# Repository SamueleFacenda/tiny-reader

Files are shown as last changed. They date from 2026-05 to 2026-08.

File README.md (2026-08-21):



<!-- PROJECT SHIELDS -->
[][contributors-url]
[][forks-url]
[][stars-url]
[][issues-url]
[][license-url]
[][workflow-url]

<!-- PROJECT LOGO -->
<div align="center">
    <a href="https://github.com/SamueleFacenda/tiny-reader">
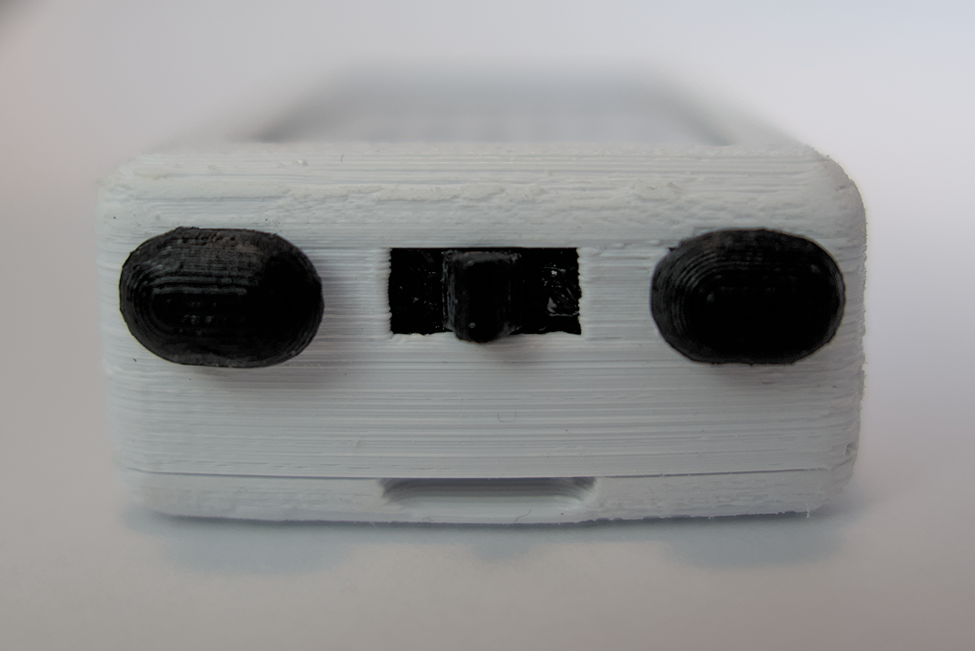
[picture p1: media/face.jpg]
        
    </a>
    <h3 align="center">TinyReader</h3>
    <p align="center">
        TinyReader is a small and easy to assembly e-book reader. 
        <br />
        It is intended for mobile reading, it's highly pocketable and supports wireless ebooks transfer. 
        <br />
        <a href="https://github.com/SamueleFacenda/tiny-reader"><strong>Explore the docs »</strong></a>
        <br />
        <br />
        <a href="#gallery">View Pictures</a>
        &middot;
        <a href="https://github.com/SamueleFacenda/tiny-reader/issues">Report Bug</a>
        &middot;
        <a href="https://github.com/SamueleFacenda/tiny-reader/issues">Request Feature</a>
    </p>
</div>

<!-- TABLE OF CONTENTS -->
<details>
    <summary>Table of Contents</summary>
    <ol>
        <li>
            <a href="#about-the-project">About The Project</a>
            <ul>
                <li><a href="#built-with">Built With</a></li>
            </ul>
        </li>
        <li>
            <a href="#getting-started">Getting Started</a>
            <ul>
                <li><a href="#prerequisites">Prerequisites</a></li>
                <li><a href="#installation">Installation</a></li>
            </ul>
        </li>
        <li><a href="#docs">Docs</a></li>
        <li><a href="#usage">Usage</a></li>
        <li><a href="#roadmap">Roadmap</a></li>
        <li><a href="#contributing">Contributing</a></li>
        <li><a href="#license">License</a></li>
        <li><a href="#contact">Contact</a></li>
        <li><a href="#acknowledgments">Acknowledgments</a></li>
        <li><a href="#star-history">Star History</a></li>
        <li><a href="#gallery">Gallery</a></li>
    </ol>
</details>

<!-- ABOUT THE PROJECT -->
## About The Project

<div style="width:40%; margin: auto;">

e reader size in hand
</div>

TinyReader is a small and easy to assembly e-book reader. It is intended for mobile reading, it's 
highly pocketable and supports wireless ebooks transfer. 

The project is experimental and practical rather than polished. Mechanical fit, battery choice, and power behavior depend on the exact hardware configuration and enclosure you build around it.

Features:
- low battery usage thanks to e-ink display and automatic deep sleep
- custom font with latin-1 encoding support
- fast page turning thanks to partial refreshes
- high readability: the font is actually bigger than a normal book font,
combined with a small display which requires minimal eye movement it results
in an high read comfort.

<p align="right">(<a href="#readme-top">back to top</a>)</p>

### Built With

* Arduino CLI
* ESP32 platform support through Nix
* LittleFS
* GxEPD2
* Adafruit GFX Library
* ArduinoJson
* OpenSCAD for enclosure work

### Hardware and cost

TinyReader primary goals were to build a pocketable and cheap ebooks reader.
The total cost is lower than 30€ (20€ without expeditions), the components used are:
- [CrowPanel ESP32 2.13 display board](https://www.elecrow.com/crowpanel-esp32-2-13-e-paper-hmi-display-with-122-250-resolution-black-white-color-driven-by-spi-interface.html): 11.9$
- A 700/800mAh LiPo battery (602060 or 603040): <10€
- 3d printed enclosure: <0.1€

<p align="right">(<a href="#readme-top">back to top</a>)</p>

<!-- GETTING STARTED -->
## Getting Started

The repository includes a Nix flake, so the Arduino toolchain and project dependencies can be gathered with `nix develop`.

The scad source is available here or the rendered stl can be downloaded [directly from printables](https://www.printables.com/model/1741918-tinyreader-case-elecrow-crowpanel-esp32-213).

### Prerequisites

* Nix with flakes enabled
* The CrowPanel ESP32 2.13 E-Paper HMI display board
* A suitable LiPo battery

### Installation

1. Clone the repo
     ```sh
     git clone https://github.com/SamueleFacenda/tiny-reader.git
     ```
2. Enter the development shell
     ```sh
     nix develop
     ```
3. Compile the sketch with Arduino CLI
     ```sh
     arduino-cli compile --fqbn esp32:esp32:esp32s3
     ```
4. Flash the firmware to the board (port may vary)
    ```sh
    arduino-cli upload -p /dev/ttyUSB0 --fqbn esp32:esp32:esp32s3 --verbose 
    ```

The flake provides the Arduino CLI, ESP32 board packages, Python serial support, and OpenSCAD.

The repository ships a [partitions.csv](partitions.csv) that drops OTA and hands the whole 8MB
flash to books, giving the library 6.62MB where the stock layout allows 1.44MB. That needs one
extra piece: the bootloader the ESP32 core builds declares 4MB and cannot be corrected while
flashing, so a table this large would not boot with it. The flake regenerates a correct one and
the development shell drops it in as `bootloader.bin`, which is why `nix develop` (or direnv) is
required before flashing rather than merely convenient. The first flash with this table
invalidates any filesystem already on the device: the reader shows a LittleFS error on boot, hold
the OK button for a couple of seconds to format it, then upload the books again.

### Assembly

No tool is actually required for the device assembly. Some more work might be required depending on
the battery size.

The board features a non so common SH1.0-2Pin battery socket so an adaptor might be necessary.

If you are using a 603040 battery you might want to remove the UART and GPIO ports to reduce the
device height. For 602060 batteries it's not necessary, they fit between the ports (but have smaller
capacity)

<p align="right">(<a href="#readme-top">back to top</a>)</p>

## Docs

* [tiny-reader.ino](tiny-reader.ino) is the Arduino entrypoint. It wires the display, input, storage, and Wi-Fi flow together.
* [tiny_reader_2-13_case.scad](tiny_reader_2-13_case.scad) is the OpenSCAD enclosure model. You can find the rendered version
[here on pritables](https://www.printables.com/model/1741918-tinyreader-case-elecrow-crowpanel-esp32-213).
* The OpenSCAD model references a CrowPanel board STL for fit checking and conversion. The board asset can be converted from the vendor archive at [00-2-13_view_asm.rar](https://github.com/Elecrow-RD/CrowPanel-ESP32-2.13-E-paper-HMI-Display-with-122-250/blob/ca6f62e88c83c108be3904d36e00ded4f55bb68f/3D%20file/00-2-13_view_asm.rar).
* The firware is built with customization in mind, take a look at [the config file](src/Config.h) for
all the available customization options (other boards might be supported as well). Setting
`LEFT_HANDED` there rotates the screen and swaps the button pairs for holding the device the
other way round.

<!-- USAGE EXAMPLES -->
## Usage

1. Flash the sketch to the board.
2. Upload plain text books through the Wi-Fi page. The page converts them in the browser:
UTF-8 becomes latin-1 (accents are kept, typographic quotes and dashes are flattened),
hyphenated line breaks are rejoined, and paragraphs are unwrapped so the reader can fill
every line of the small screen.
3. Use the physical buttons to navigate the library, reading view, and status screens. Presses
are never lost while the screen is updating, so the lever can be pushed repeatedly to scroll
several pages ahead in one refresh.
4. Press OK while reading for a deep clean refresh, which clears the ghosting that sunlight
makes visible.
5. Let the device enter deep sleep when idle to preserve battery life. Between page turns it
already drops into light sleep, waking on a button.
6. Wake from the deep sleep using the `home` button.

See the source files for the screen flow and button mapping.

<p align="right">(<a href="#readme-top">back to top</a>)</p>

<!-- ROADMAP -->
## Roadmap

- Improve the library and book navigation flow.
- Refine the Wi-Fi user interface.
- Add a dedicated sleep-screen experience.
- Improve battery status reporting when a usable ADC input is available.
- Update only the necessary parts of the screen during Wi-Fi uptime refreshes.
- Evaluate compressed book storage to reduce flash usage.
- Reduce friction in navigation and return paths between screens.

See the [open issues](https://github.com/SamueleFacenda/tiny-reader/issues) for the current list of planned work.

<p align="right">(<a href="#readme-top">back to top</a>)</p>

<!-- CONTRIBUTING -->
## Contributing

Contributions are welcome. If you have an idea that would make TinyReader better, open an issue or submit a pull request with a clear description of the change.

1. Fork the Project
2. Create your Feature Branch (`git checkout -b feature/AmazingFeature`)
3. Commit your Changes (`git commit -m 'Add some AmazingFeature'`)
4. Push to the Branch (`git push origin feature/AmazingFeature`)
5. Open a Pull Request

<p align="right">(<a href="#readme-top">back to top</a>)</p>

<!-- LICENSE -->
## License

Distributed under the EUPL. See [LICENSE.md](LICENSE.md) for more information.

<p align="right">(<a href="#readme-top">back to top</a>)</p>

<!-- CONTACT -->
## Contact

Project Link: [https://github.com/SamueleFacenda/tiny-reader](https://github.com/SamueleFacenda/tiny-reader)

Use GitHub issues for bugs, feature requests, and build questions.

<p align="right">(<a href="#readme-top">back to top</a>)</p>

<!-- ACKNOWLEDGMENTS -->
## Acknowledgments

* [Original case designer](https://www.printables.com/model/1566902-case-for-crowpanel-213-epaper)
* [CrowPanel ESP32 2.13 E-Paper HMI display](https://example.com/tinyreader-crowpanel-esp32-2-13)
* [Nix](https://nixos.org/)
* [Arduino CLI](https://arduino.github.io/arduino-cli/latest/)

<p align="right">(<a href="#readme-top">back to top</a>)</p>

<!-- GALLERY -->
## Gallery

### TinyReader UI
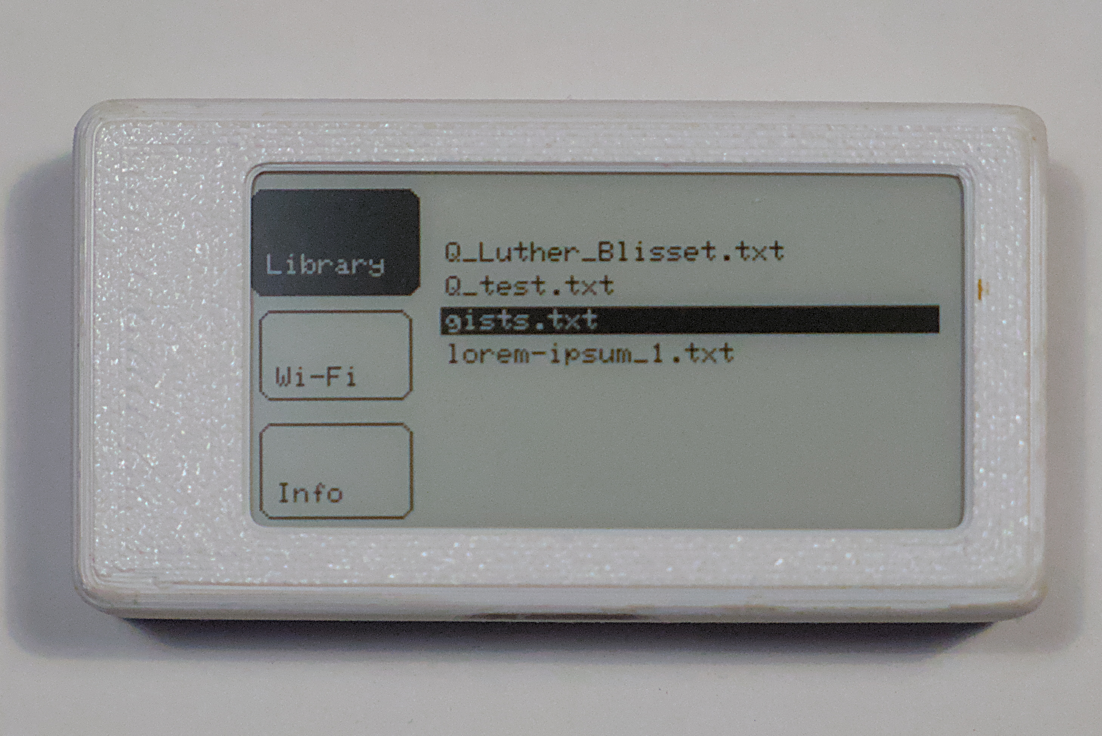
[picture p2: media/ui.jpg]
e reader ui


### TinyReader buttons interface
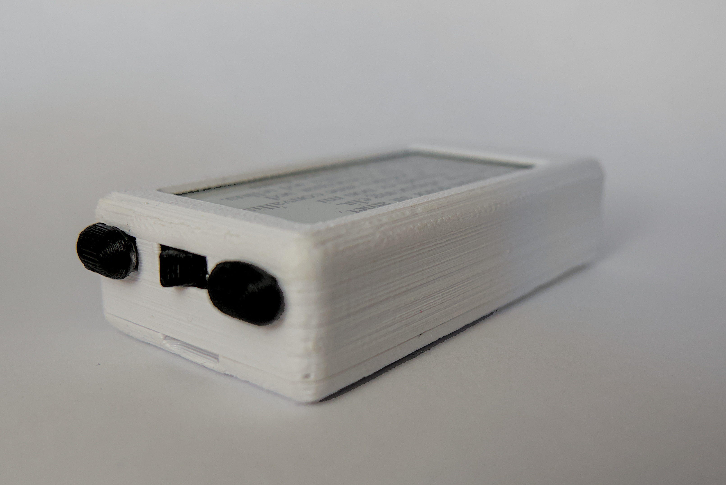
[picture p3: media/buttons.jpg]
buttons view


### TinyReader internal design
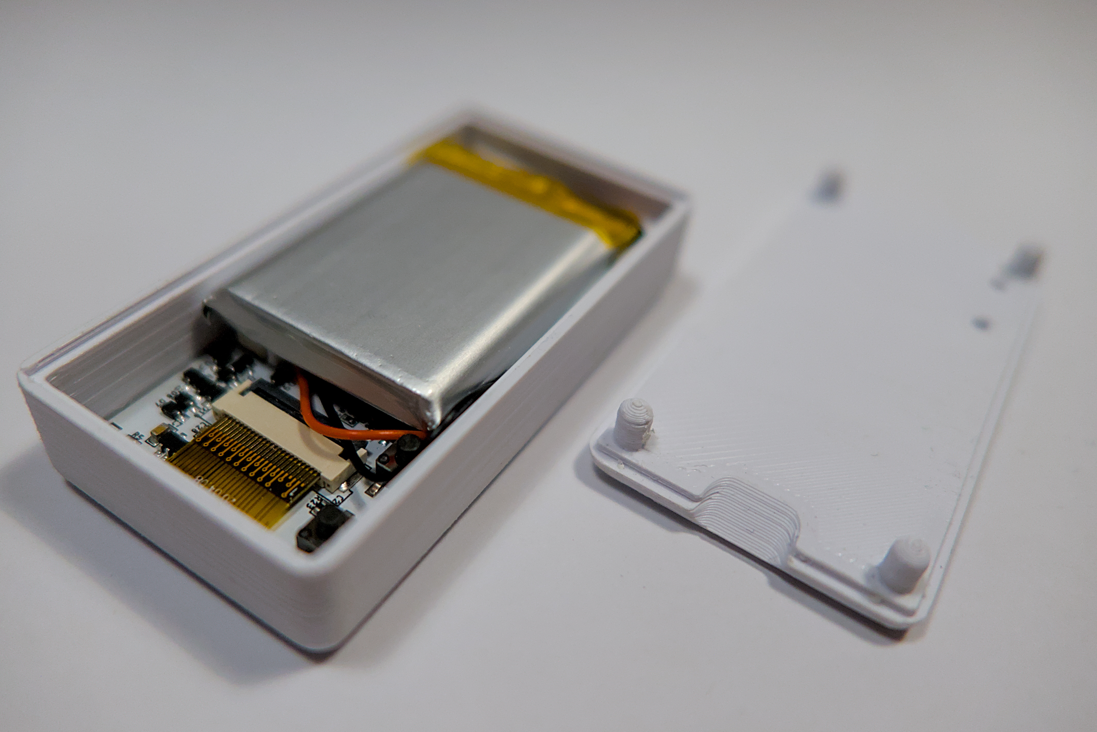
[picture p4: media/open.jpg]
board opened


## Star History

Star History Chart (https://www.star-history.com/#SamueleFacenda/tiny-reader&Date)

<!-- MARKDOWN LINKS & IMAGES -->
[contributors-shield]: https://img.shields.io/github/contributors/SamueleFacenda/tiny-reader.svg?style=for-the-badge
[contributors-url]: https://github.com/SamueleFacenda/tiny-reader/graphs/contributors
[forks-shield]: https://img.shields.io/github/forks/SamueleFacenda/tiny-reader.svg?style=for-the-badge
[forks-url]: https://github.com/SamueleFacenda/tiny-reader/network/members
[stars-shield]: https://img.shields.io/github/stars/SamueleFacenda/tiny-reader.svg?style=for-the-badge
[stars-url]: https://github.com/SamueleFacenda/tiny-reader/stargazers
[issues-shield]: https://img.shields.io/github/issues/SamueleFacenda/tiny-reader.svg?style=for-the-badge
[issues-url]: https://github.com/SamueleFacenda/tiny-reader/issues
[license-shield]: https://img.shields.io/github/license/SamueleFacenda/tiny-reader.svg?style=for-the-badge
[license-url]: https://github.com/SamueleFacenda/tiny-reader/blob/main/LICENSE.md
[workflow-shield]: https://img.shields.io/github/actions/workflow/status/SamueleFacenda/tiny-reader/main.yml?style=for-the-badge
[workflow-url]: https://github.com/SamueleFacenda/tiny-reader/actions/workflows/main.yml

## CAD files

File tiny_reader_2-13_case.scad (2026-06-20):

ZERO_GAP = $preview ? 0.1 : 0; // Put at zero in rendering, used to prevent zero thickness issues in difference() operations during preview
EPS = 0.01; // Small but non zero value

module rounded_trapezoid(w, h, r, r2 = -1, off = -1) {
    off_val = off < 0 ? h : off;
    r2_val = r2 < 0 ? r + off_val : r2;
    
    translate([r, r, -ZERO_GAP])
        hull() {
            minkowski() {
                cube([w[0] - 2*r, w[1] - 2*r, EPS]);
                cylinder(h=EPS, r=r);
            }
            translate([-off_val + (r2_val - r), -off_val + (r2_val - r), h + 2*ZERO_GAP - 2*EPS])
                minkowski() {
                    cube([w[0] - 2*r2_val + 2*off_val, w[1] - 2*r2_val + 2*off_val, EPS]);
                    cylinder(h=EPS, r=r2_val);
                }
        };
}

module rounded_cube(w, r) {
    translate([r, r, 0])
        minkowski() {
            cube([w[0] - 2*r, w[1] - 2*r, w[2] - r]);
            difference() { // half sphere
                sphere(r = r);
                translate([-r, -r, -2*r]) 
                    cube([2*r, 2*r, 2*r]); 
            }
        };
}

module corners(offset_val = 2.2) {
    inset = wall + offset_val;
    translate([inset, inset, 0]) children();
    translate([total_w - inset, inset, 0]) children();
    translate([total_w - inset, total_d - inset, 0]) children();
    translate([inset, total_d - inset, 0]) children();
}

buttons_base_w = 6;
buttons_base_d = 4;
buttons_base_h = 0.6;
buttons_base_tolerance = 0.5;
buttons_base_diagonal = sqrt(buttons_base_w^2 + buttons_base_d^2);

module tactile_button() {
    union() {
        // 2.0 is wall, don't want to move the declaration
        cylinder(h=2*buttons_base_h + buttons_base_tolerance, r=(buttons_base_d-buttons_base_tolerance)/2);
        translate([0,0,buttons_base_tolerance + 2*buttons_base_h])
            minkowski() {
                cube([EPS, 3, EPS], center=true);
                difference() {
                    sphere(r=buttons_base_w/2);
                    translate([0,0,-buttons_base_w/2])
                        cube([buttons_base_w, buttons_base_w, buttons_base_w], center=true); 
                }
            }
        translate([-(buttons_base_w - buttons_base_tolerance)/2,-(buttons_base_d - buttons_base_tolerance)/2,-buttons_base_h])
            cube([buttons_base_w - buttons_base_tolerance, buttons_base_d - buttons_base_tolerance, buttons_base_h]);
    }
}

// --- BOARD SPECIFICATIONS ---
pcb_w = 62.8;         // PCB Width
pcb_d = 31.0;         // PCB Depth
// pcb_h = 10.7; // real height
// pcb_h = 10.7 + 6.0;    // battery plus full pcb
pcb_h = 6.5 + 6.0 + 1.0;    // battery plus pcb with ports removed
pcb_r_h = 6.8; // Height of the buttons side
pcb_l_h = 2.5; // Height of the left side

// --- FRONT BEZEL (SCREEN EDGES) ---
bezel_l = 4.5;         // Left bezel
bezel_r = 8.8;         // Right bezel
bezel_tb = 3.0;        // Top/Bottom bezel
bezel_thickness = 0.8; // Front wall thickness

// --- USB-C POSITION ---
// X position is calculated from the left edge (bezel_l)
usb_x_pos = 32.2;
usb_from_top = 4.9;
usb_w = 11.0;
usb_h = 4.5;
usb_corner_r = 1.5;

// Buttons position (on the left side, centered vertically)
buttons_w = 31.0; // width with some margin
buttons_from_bezel = 3.0; // distance from the top (without bezel) to buttons top
buttons_h = 4.0; // height of the buttons area
buttons_from_side = 1.4; // from the aperture side to the side buttons
side_buttons_h = 0.6; // height of the side buttons

// Opening hole on the base
opening_w = 10.0;
opening_r = 2.0;

// Lever button
lever_button_h = 5.0;
lever_button_w = 3.4;
lever_button_d = buttons_base_d;
lever_button_movement = 2.3; // How much can the lever move left and right
lever_button_base_margin = 1.0;
lever_button_base_h = 0.6;
lever_button_x = 0.6; // How into the wall must the button stay
lever_w = 2.8; // Width of the board lever button (2.21 real)
lever_h = 2.0; // Height of the board lever button (in the button cover)
lever_radius = 7.0;
lever_vertical_space = 0.4;
lever_button_rounding_ratio = 0.2; // radius of the top cylinder compared to the slope height

// Internal buttons position
internal_buttons_r = 1.2;
boot_from_wall = 4.7 + internal_buttons_r; // distance from the wall to the center of the boot button
reset_from_wall = 15.2 + internal_buttons_r; // distance from the wall to the center of the reset button
internal_buttons_y = 2.5 + internal_buttons_r; // distance from the front edge to the center of the buttons

// --- ADJUSTMENT PARAMETERS (SNUG FIT) ---
wall = 2.0;           // Wall thickness
gap = 0.8;            // Total internal clearance (for a tight fit)
corner_r = 3.0;       // Corner radius
pin_dia = 3.6;        // Pin diameter
pin_h = pcb_h - pcb_r_h - pin_dia/2 - 0.1; // Pin height
tolerance = 0.25;     // Tolerance for pins (adjust as needed)

// --- BASE SETTINGS ---
base_h = corner_r;

$fn = 60;

// Total External Dimensions
total_w = pcb_w + 2*wall + gap;
total_d = pcb_d + 2*wall + gap;
total_h = pcb_h + bezel_thickness;

// --- MAIN BODY (CASE) ---
module main_body() {
    if ($preview) {
        translate([31.8 + wall, 15.85 + wall, pcb_h - 1.7])
            rotate([90,0,90])
                #import("output.stl");
    }
    difference() {
        // External Block
        rounded_cube([total_w, total_d, total_h], corner_r);

        // PCB Cavity
        translate([wall, wall, -ZERO_GAP])
            cube([pcb_w + gap, pcb_d + gap, total_h - bezel_thickness + ZERO_GAP*2]);

        // Screen Window (Adjusted for Left and Right)
        // Window Width = PCB_W - (Left Bezel + Right Bezel)
        translate([wall + bezel_l, wall + bezel_tb, total_h - bezel_thickness])
            rounded_trapezoid([pcb_w - (bezel_l + bezel_r), pcb_d - 2*bezel_tb], bezel_thickness, bezel_thickness);


        // Side buttons slot
        translate([0, (total_d - buttons_w) / 2 + buttons_from_side, total_h - bezel_thickness - buttons_from_bezel - buttons_h])
            union() {
                cube([wall + ZERO_GAP, buttons_base_w, buttons_base_d]);
                translate([buttons_base_h, (buttons_base_w - buttons_base_d)/2, (buttons_base_d - buttons_base_w)/2])
                    cube([wall, buttons_base_d, buttons_base_w]);
                translate([2*buttons_base_h, (buttons_base_w - buttons_base_diagonal)/2, (buttons_base_d - buttons_base_diagonal)/2])
                    difference() {
                        cube([wall, buttons_base_diagonal, buttons_base_diagonal]);
                        cube([wall, (buttons_base_diagonal - buttons_base_d)/2, (buttons_base_diagonal - buttons_base_d)/2]);
                    }
                }
        translate([0, (total_d + buttons_w) / 2 - buttons_from_side - buttons_base_w, total_h - bezel_thickness - buttons_from_bezel - buttons_h])
            union() {
                cube([wall + ZERO_GAP, buttons_base_w, buttons_base_d]);
                translate([buttons_base_h, (buttons_base_w - buttons_base_d)/2, (buttons_base_d - buttons_base_w)/2])
                    cube([wall, buttons_base_d, buttons_base_w]);
                translate([2*buttons_base_h, (buttons_base_w - buttons_base_diagonal)/2, (buttons_base_d - buttons_base_diagonal)/2])
                    difference() {
                        cube([wall, buttons_base_diagonal, buttons_base_diagonal]);
                        translate([0, buttons_base_diagonal/2 + buttons_base_d/2, 0])
                        cube([wall, (buttons_base_diagonal - buttons_base_d)/2, (buttons_base_diagonal - buttons_base_d)/2]);
                    }
            }
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

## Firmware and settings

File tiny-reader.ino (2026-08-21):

#include <Arduino.h>
#include <LittleFS.h>
#include <vector>

#include "src/Config.h"
#include "src/Input.h"
#include "src/Storage.h"
#include "src/Ui.h"
#include "src/WebPortal.h"

#include <esp_sleep.h>
#include <esp_system.h>

EpdDisplay display(EpdDriver(Config::PIN_EPD_CS, Config::PIN_EPD_DC, Config::PIN_EPD_RST, Config::PIN_EPD_BUSY));

enum class ScreenId : uint8_t {
  Reader = 0,
  MenuLibrary = 1,
  ChooseBook = 2,
  MenuWifi = 3,
  MenuInfo = 4,
  WifiSettings = 5,
  Error = 6
};

struct ReaderState {
  File file;
  String path;
  size_t size = 0;
  uint32_t pagePos = 0;
  uint32_t nextPagePos = 0;
  std::vector<uint32_t> history;
};

static ReaderState reader;
// One page of raw bytes, reused for both drawing and paintless measurement.
static char pageBuffer[Config::READ_BUFFER_SIZE];
static ButtonManager buttons;
static ScreenId screen = ScreenId::MenuLibrary;
static unsigned long lastActivity = 0;
// What the portal screen currently shows, so it repaints on a change rather than on a
// timer: a paint costs 600-800ms of loop time, which starves handleClient() and loads
// the panel charge pump while the radio is transmitting.
static uint32_t wifiShownMinutes = UINT32_MAX;
static size_t wifiShownClients = SIZE_MAX;
static uint16_t wifiPartialsSinceFull = 0;
static uint8_t partialsSinceFull = 0;
static std::vector<BookInfo> libraryBooks;
static int libraryIndex = 0;
static int libraryScroll = 0;
RTC_DATA_ATTR static uint8_t sleepResumeMode = 0; // 0=unknown, 1=reader, 2=menu

static const char* resetReasonName(esp_reset_reason_t reason) {
  switch (reason) {
    case ESP_RST_POWERON:
      return "power-on";
    case ESP_RST_EXT:
      return "external";
    case ESP_RST_SW:
      return "software";
    case ESP_RST_PANIC:
      return "panic";
    case ESP_RST_INT_WDT:
      return "interrupt-watchdog";
    case ESP_RST_TASK_WDT:
      return "task-watchdog";
    case ESP_RST_WDT:
      return "other-watchdog";
    case ESP_RST_DEEPSLEEP:
      return "deep-sleep";
    case ESP_RST_BROWNOUT:
      return "brownout";
    case ESP_RST_SDIO:
      return "sdio";
    default:
      return "unknown";
  }
}

static void updateActivity() {
  lastActivity = millis();
}

static const char* screenName(ScreenId id) {
  switch (id) {
    case ScreenId::Reader:
      return "Reader";
    case ScreenId::MenuLibrary:
      return "MenuLibrary";
    case ScreenId::ChooseBook:
      return "ChooseBook";
    case ScreenId::MenuWifi:
      return "MenuWifi";
    case ScreenId::MenuInfo:
      return "MenuInfo";
    case ScreenId::WifiSettings:
      return "WifiSettings";
    case ScreenId::Error:
      return "Error";
    default:
      return "Unknown";
  }
}

static void logState(const char* tag) {
  Serial.printf(
    "%s screen=%s reader=%s pos=%u books=%u idx=%d scroll=%d portal=%s uptime=%lu heap=%u min=%u maxalloc=%u\n",
    tag,
    screenName(screen),
    reader.file ? "open" : "closed",
    static_cast<unsigned>(reader.pagePos),
    static_cast<unsigned>(libraryBooks.size()),
    libraryIndex,
    libraryScroll,
    webPortalActive() ? "on" : "off",
    static_cast<unsigned long>(webPortalUptimeMs()),
    static_cast<unsigned>(ESP.getFreeHeap()),
    static_cast<unsigned>(ESP.getMinFreeHeap()),
    static_cast<unsigned>(ESP.getMaxAllocHeap())
  );
}

// Reads one page worth of raw bytes at pos into pageBuffer, returning the count.
static size_t readPageAt(uint32_t pos) {
  if (!reader.file) {
    return 0;
  }
  reader.file.seek(pos);
  int bytesRead = reader.file.read(reinterpret_cast<uint8_t*>(pageBuffer), sizeof(pageBuffer));
  return (bytesRead > 0) ? static_cast<size_t>(bytesRead) : 0;
}

// Where the page starting at pos would end, without drawing anything.
static uint32_t pageEndAt(uint32_t pos) {
  size_t available = readPageAt(pos);
  size_t consumed = uiMeasurePage(pageBuffer, available);
  uint32_t end = pos + static_cast<uint32_t>(consumed);
  return (end > reader.size) ? reader.size : end;
}

// Keeps the selection inside the library and the scroll window around it.
static void clampLibrarySelection() {
  if (libraryBooks.empty()) {
    libraryIndex = 0;
    libraryScroll = 0;
    return;
  }

  const int lastIndex = static_cast<int>(libraryBooks.size()) - 1;
  libraryIndex = constrain(libraryIndex, 0, lastIndex);

  const int visible = uiLayout().maxLines;
  if (libraryIndex < libraryScroll) {
    libraryScroll = libraryIndex;
  } else if (libraryIndex >= libraryScroll + visible) {
    libraryScroll = libraryIndex - visible + 1;
  }
}

static void refreshLibrary() {
  libraryBooks = storageListBooks();

  const String currentBook = storageGetCurrentBook();
  for (size_t i = 0; i < libraryBooks.size() && currentBook.length() > 0; ++i) {
    if (libraryBooks[i].path == currentBook) {
      libraryIndex = static_cast<int>(i);
      break;
    }
  }
  clampLibrarySelection();
}

static ScreenId previousMenu(ScreenId target) {
  switch (target) {
    case ScreenId::MenuLibrary:
      return ScreenId::MenuInfo;
    case ScreenId::MenuWifi:
    case ScreenId::WifiSettings:
      return ScreenId::MenuLibrary;
    case ScreenId::MenuInfo:
      return ScreenId::MenuWifi;
    default:
      return ScreenId::MenuLibrary;
  }
}

static ScreenId nextMenu(ScreenId target) {
  switch (target) {
    case ScreenId::MenuLibrary:
      return ScreenId::MenuWifi;
    case ScreenId::MenuWifi:
    case ScreenId::WifiSettings:
      return ScreenId::MenuInfo;
    case ScreenId::MenuInfo:
      return ScreenId::MenuLibrary;
    default:
      return ScreenId::MenuLibrary;
  }
}

static bool isMenuScreen(ScreenId target) {
  return target == ScreenId::MenuLibrary || target == ScreenId::MenuWifi || target == ScreenId::MenuInfo || target == ScreenId::WifiSettings;
}

static void openBook(const String& path, bool resetPos) {
  if (reader.file) {
    reader.file.close();
  }
  reader.path = storageNormalizeBookPath(path);
  reader.file = LittleFS.open(reader.path, "r");
  if (!reader.file) {
    Serial.printf("Failed to open book: %s\n", reader.path.c_str());
    reader.size = 0;
    return;
  }

  reader.size = reader.file.size();
  ReadingPosition saved;
  if (!resetPos) {
    saved = storageLoadPosition(reader.path, reader.size);
  }
  reader.pagePos = saved.pos;
  reader.nextPagePos = saved.pos;
  reader.file.seek(reader.pagePos);
  reader.history = saved.history;
  storageSetCurrentBook(reader.path);
  partialsSinceFull = 0;
  Serial.printf("Opened book: %s (%u bytes)\n", reader.path.c_str(), static_cast<unsigned>(reader.size));
}

static void saveReaderPosition() {
  storageSavePosition(reader.path, reader.pagePos, reader.history);
}

static void renderCurrentPage(bool allowPartial) {
  if (!reader.file) {
    return;
  }
  size_t available = readPageAt(reader.pagePos);
  saveReaderPosition();

  ReaderView view;
  view.text = pageBuffer;
  view.textLen = available;
  view.bytesConsumed = 0;
  view.progressPercent = (reader.size > 0)
                           ? static_cast<uint8_t>(min<uint32_t>(100, (reader.pagePos * 100UL) / reader.size))
                           : 0;

  // A full draw every PARTIAL_REFRESH_LIMIT paints clears the ghosting the partial
  // updates leave behind. Counted in paints, not presses, so fast scrolling cannot
  // skip past it.
  const bool usePartial = allowPartial && (partialsSinceFull < Config::PARTIAL_REFRESH_LIMIT);
  uiDrawReader(display, view, usePartial);

  // The bytes actually rendered are what the next page starts from, clamped to EOF.
  reader.nextPagePos = reader.pagePos + view.bytesConsumed;
  if (reader.nextPagePos >= reader.size) {
    reader.nextPagePos = reader.size;
  }

  if (usePartial) {
    partialsSinceFull++;
  } else {
    partialsSinceFull = 0;
  }
  Serial.printf("Rendered page at %u next=%u consumed=%u heap=%u maxalloc=%u\n",
                static_cast<unsigned>(reader.pagePos),
                static_cast<unsigned>(reader.nextPagePos),
                static_cast<unsigned>(view.bytesConsumed),
                static_cast<unsigned>(ESP.getFreeHeap()),
                static_cast<unsigned>(ESP.getMaxAllocHeap()));
}

// Advances count pages but paints only the one we land on: the intermediate boundaries
// are measured without touching the panel, so holding the lever scrolls.
static void advancePages(uint8_t count) {
  if (!reader.file || count == 0) {
    return;
  }
  uint8_t skipped = 0;
  for (uint8_t i = 0; i < count; ++i) {
    if (reader.nextPagePos >= reader.size || reader.nextPagePos == reader.pagePos) {
      break;   // end of book, or a page that consumed nothing
    }
    reader.history.push_back(reader.pagePos);
    if (reader.history.size() > Config::READER_HISTORY_MAX) {
      reader.history.erase(reader.history.begin());
    }
    reader.pagePos = reader.nextPagePos;
    skipped++;
    if (i + 1 < count) {
      reader.nextPagePos = pageEndAt(reader.pagePos);
    }
  }
  if (skipped == 0) {
    return;
  }
  if (skipped > 1) {
    Serial.printf("Skipped %u pages without painting\n", static_cast<unsigned>(skipped - 1));
  }
  renderCurrentPage(true);
}

static void goBackPages(uint8_t count) {
  if (reader.history.empty() || count == 0) {
    return;
  }
  while (count > 0 && !reader.history.empty()) {
    reader.pagePos = reader.history.back();
    reader.history.pop_back();
    count--;
  }
  reader.nextPagePos = reader.pagePos;
  renderCurrentPage(true);
}

// A white flash plus a full re-render: the strongest cleanup for the sun ghosting the
// panel offers from firmware.
static void deepClean() {
  Serial.println("Deep clean refresh");
  display.clearScreen();
  partialsSinceFull = 0;
  renderCurrentPage(false);
}

static float readBatteryVoltage() {
  if (Config::BATTERY_ADC_PIN < 0) {
    return -1.0f;
  }
  uint16_t raw = analogRead(Config::BATTERY_ADC_PIN);
  float v = (static_cast<float>(raw) / Config::BATTERY_ADC_MAX) * Config::BATTERY_ADC_REF;
  return v * Config::BATTERY_DIVIDER;
}

static int batteryPercentFromVoltage(float v) {
  if (v < 0.0f) {
    return 0;
  }
  float clamped = min(max(v, Config::BATTERY_MIN_V), Config::BATTERY_MAX_V);
  float pct = (clamped - Config::BATTERY_MIN_V) / (Config::BATTERY_MAX_V - Config::BATTERY_MIN_V);
  return static_cast<int>(pct * 100.0f + 0.5f);
}

static void showScreen(ScreenId target) {
  if (target == ScreenId::Reader && !reader.file) {
    Serial.println("showScreen: no book open, falling back to MenuLibrary");
    target = ScreenId::MenuLibrary;
  }
  Serial.printf("showScreen: %s -> %s\n", screenName(screen), screenName(target));
  screen = target;

  switch (screen) {
    case ScreenId::Reader:
      renderCurrentPage(false);
      break;
    case ScreenId::MenuLibrary:
      refreshLibrary();
      uiDrawLibrary(display, libraryBooks, -1, libraryScroll);   // no selection: menu has focus
      break;
    case ScreenId::ChooseBook:
      refreshLibrary();
      uiDrawLibrary(display, libraryBooks, libraryIndex, libraryScroll);
      break;
    case ScreenId::MenuWifi:
      uiDrawWifiOff(display);
      break;
    case ScreenId::MenuInfo: {
      const float volts = readBatteryVoltage();
      uiDrawInfo(display, storageGetStats(), volts, batteryPercentFromVoltage(volts));
      break;
    }
    case ScreenId::WifiSettings:
      wifiPartialsSinceFull = 0;
      wifiShownMinutes = webPortalUptimeMs() / 60000;
      wifiShownClients = webPortalClientCount();
      uiDrawWifiSettings(display, webPortalActive(), webPortalIp(), Config::WIFI_SSID, Config::WIFI_PASS,
                         webPortalUptimeMs(), webPortalClientCount(), false);
      break;
    case ScreenId::Error:
      break;
  }

  logState("drawn");
}

static void onUploadComplete(const String& path, bool success) {
  if (!success) {
    Serial.println("Upload failed");
    return;
  }
  Serial.printf("Upload complete: %s\n", path.c_str());
  storageEnsureDirs();
  refreshLibrary();
  updateActivity();
}

// Blocks on the error screen until the filesystem mounts or the user formats it.
static void ensureStorageReady() {
  if (storageBegin(false)) {
    return;
  }
  screen = ScreenId::Error;
  uiDrawError(display, "LittleFS error", "Mount failed", "Hold OK to format");

  unsigned long okStart = 0;
  while (true) {
    buttons.update();
    if (buttons.isDown(ButtonId::Ok)) {
      if (okStart == 0) {
        okStart = millis();
      }
      if (millis() - okStart > Config::FS_FORMAT_HOLD_MS) {
        Serial.println("Formatting LittleFS...");
        LittleFS.format();
        ESP.restart();
      }
    } else {
      okStart = 0;
    }

    if (buttons.consumeShortPress(ButtonId::Exit)) {
      if (storageBegin(true)) {
        return;
      }
      uiDrawError(display, "LittleFS error", "Mount failed", "Press Exit to retry");
    }
    delay(20);
  }
}

// How long the loop may sleep before it has work to do again.
static uint64_t microsecondsUntilDeadline() {
  const unsigned long elapsed = millis() - lastActivity;
  if (elapsed >= Config::INACTIVITY_SLEEP_MS) {
    return 0;
  }
  return static_cast<uint64_t>(Config::INACTIVITY_SLEEP_MS - elapsed) * 1000ULL;
}

// Reading a page is idle time, so the CPU sleeps until a button wakes it instead of
// spinning until the deep sleep timeout. RAM and execution state survive, so the loop
// carries on. ButtonManager owns the wake arming, which collides with the press
// interrupt.
static void maybeLightSleep() {
  if (webPortalActive() || screen == ScreenId::Error) {
    return;
  }
  if (buttons.anyPending() || buttons.anyRawDown()) {
    return;
  }
  const uint64_t us = microsecondsUntilDeadline();
  if (us < Config::LIGHT_SLEEP_MIN_US) {
    return;
  }

  buttons.prepareForLightSleep();
  esp_sleep_enable_timer_wakeup(us);

  Serial.flush();   // the UART would otherwise garble mid-line
  esp_light_sleep_start();

  buttons.resumeAfterLightSleep();
}

static void maybeDeepSleep() {
  if (screen == ScreenId::Error) {
    return;
  }
  if (webPortalActive()) {
    return;
  }
  if (millis() - lastActivity < Config::INACTIVITY_SLEEP_MS) {
    return;
  }
  Serial.println("Entering deep sleep");
  sleepResumeMode = (screen == ScreenId::Reader) ? 1 : 2;
  if (screen == ScreenId::Reader && reader.file) {
    saveReaderPosition();
  }
  display.hibernate();
  // Clear whatever light sleep armed, then wake from ext0 alone. Disabling the sources
  // one at a time logs an error for each that is already inactive.
  esp_sleep_disable_wakeup_source(ESP_SLEEP_WAKEUP_ALL);
  esp_sleep_enable_ext0_wakeup((gpio_num_t)Config::PIN_WAKE, 0);
  delay(50);
  esp_deep_sleep_start();
}

void setup() {
  Serial.begin(115200);

  unsigned long serialWaitStart = millis();
  while (!Serial && millis() - serialWaitStart < 1200) {
    delay(10);
  }
  Serial.printf("TinyReader boot, last reset: %s\n", resetReasonName(esp_reset_reason()));

  pinMode(Config::PIN_EPD_POWER, OUTPUT);
  digitalWrite(Config::PIN_EPD_POWER, HIGH);

  uiInit(display);
  buttons.begin();
  Serial.printf("Buttons pullup: %s\n", Config::BUTTON_PULLUP ? "on" : "off");

  if (Config::BATTERY_ADC_PIN >= 0) {
    analogReadResolution(12);
  }

  ensureStorageReady();
  storageEnsureDirs();

  StorageStats stats = storageGetStats();
  Serial.printf("Filesystem: %u of %u bytes used\n",
                static_cast<unsigned>(stats.usedBytes),
                static_cast<unsigned>(stats.totalBytes));

  String current = storageGetCurrentBook();
  bool wokeFromSleep = (esp_sleep_get_wakeup_cause() == ESP_SLEEP_WAKEUP_EXT0);
  if (wokeFromSleep && current.length() > 0 && sleepResumeMode == 1) {
    openBook(current, false);
    showScreen(ScreenId::Reader);
  } else {
    showScreen(ScreenId::MenuLibrary);
  }

  sleepResumeMode = 0;

  lastActivity = millis();
}

// Net movement of the latched direction pair, so a burst of presses costs one repaint.
static int consumeDirection() {
  const int forward = buttons.consumePresses(ButtonId::Next);
  const int backward = buttons.consumePresses(ButtonId::Prev);
  if (forward != 0 || backward != 0) {
    Serial.printf("BTN next=%d prev=%d\n", forward, backward);
  }
  return forward - backward;
}

static void serviceWebPortal() {
  if (!webPortalActive()) {
    return;
  }
  webPortalHandle();

  // Repaint only on a change: refreshing through the SERVER_TIMEOUT_MS window would
  // starve handleClient() and load the rail while clients are associating.
  if (screen == ScreenId::WifiSettings) {
    const uint32_t minutes = webPortalUptimeMs() / 60000;
    const size_t clients = webPortalClientCount();
    if (minutes != wifiShownMinutes || clients != wifiShownClients) {
      wifiShownMinutes = minutes;
      wifiShownClients = clients;
      const bool partial = (wifiPartialsSinceFull < Config::WIFI_SETTINGS_FULL_REFRESH_EVERY);
      uiDrawWifiSettings(display, true, webPortalIp(), Config::WIFI_SSID, Config::WIFI_PASS,
                         webPortalUptimeMs(), clients, partial);
      wifiPartialsSinceFull = partial ? (wifiPartialsSinceFull + 1) : 0;
    }
  }

  if (webPortalUptimeMs() > Config::SERVER_TIMEOUT_MS) {
    webPortalStop();
    if (screen == ScreenId::WifiSettings) {
      showScreen(ScreenId::MenuWifi);
    }
  }
}

// Exit leaves the current screen: back to the book if one is open, to the menu if not.
static bool handleExit() {
  if (!buttons.consumeShortPress(ButtonId::Exit)) {
    return false;
  }
  Serial.println("BTN Exit");

  switch (screen) {
    case ScreenId::WifiSettings:
      webPortalStop();
      showScreen(ScreenId::MenuWifi);
      break;
    case ScreenId::MenuLibrary:
      showScreen(reader.file ? ScreenId::Reader : ScreenId::MenuWifi);
      break;
    case ScreenId::Error:
      break;
    default:
      showScreen(ScreenId::MenuLibrary);
      break;
  }
  return true;
}

// Next and Prev walk the menu cycle on every menu screen alike.
static bool handleMenuStep() {
  if (!isMenuScreen(screen)) {
    return false;
  }
  int steps = consumeDirection();
  if (steps == 0) {
    return false;
  }

  ScreenId target = screen;
  for (; steps > 0; --steps) {
    target = nextMenu(target);
  }
  for (; steps < 0; ++steps) {
    target = previousMenu(target);
  }
  showScreen(target);
  return true;
}

static bool handleReaderInput() {
  const int pages = consumeDirection();
  if (pages > 0) {
    advancePages(pages);
  } else if (pages < 0) {
    goBackPages(-pages);
  }

  bool acted = (pages != 0);
  if (buttons.consumeShortPress(ButtonId::Ok)) {
    Serial.println("BTN Ok");
    deepClean();
    acted = true;
  }
  return acted;
}

static bool handleChooseBookInput() {
  bool acted = false;

  const int steps = consumeDirection();
  if (steps != 0 && !libraryBooks.empty()) {
    libraryIndex += steps;
    clampLibrarySelection();
    uiDrawLibrary(display, libraryBooks, libraryIndex, libraryScroll);
    acted = true;
  }

  if (buttons.consumeShortPress(ButtonId::Ok)) {
    Serial.println("BTN Ok");
    if (libraryBooks.empty()) {
      showScreen(ScreenId::MenuLibrary);
    } else {
      openBook(libraryBooks[libraryIndex].path, false);
      showScreen(ScreenId::Reader);
    }
    acted = true;
  }
  return acted;
}

// Ok means something different on every menu: enter the library, start the portal, or
// redraw what is on screen.
static bool handleMenuOk() {
  if (!buttons.consumeShortPress(ButtonId::Ok)) {
    return false;
  }
  Serial.println("BTN Ok");

  switch (screen) {
    case ScreenId::MenuLibrary:
      showScreen(libraryBooks.empty() ? ScreenId::MenuWifi : ScreenId::ChooseBook);
      break;
    case ScreenId::MenuWifi:
      if (!webPortalActive() && !webPortalStart(onUploadComplete)) {
        // The AP failed to come up: say so rather than show credentials that nothing
        // is listening on.
        Serial.println("Web portal failed to start");
        showScreen(ScreenId::MenuWifi);
        break;
      }
      showScreen(ScreenId::WifiSettings);
      break;
    default:
      showScreen(screen);   // MenuInfo and WifiSettings just refresh
      break;
  }
  return true;
}

static bool handleScreenInput() {
  switch (screen) {
    case ScreenId::Reader:
      return handleReaderInput();
    case ScreenId::ChooseBook:
      return handleChooseBookInput();
    case ScreenId::MenuLibrary:
    case ScreenId::MenuWifi:
    case ScreenId::MenuInfo:
    case ScreenId::WifiSettings:
      return handleMenuOk();
    case ScreenId::Error:
      return false;
  }
  return false;
}

void loop() {
  buttons.update();
  serviceWebPortal();

  bool acted = handleExit();
  acted |= handleMenuStep();
  acted |= handleScreenInput();

  if (acted) {
    updateActivity();
  }

  maybeDeepSleep();
  maybeLightSleep();
}

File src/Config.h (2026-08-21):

#pragma once

#include <Arduino.h>
#include <GxEPD2_BW.h>
#include <type_traits>

#include "GxEPD2_213_JD79661.h"

namespace Config {
  // Set to true to hold the device the other way round: the screen is rotated 180
  // degrees and the button pairs a flipped grip swaps are exchanged.
  constexpr bool LEFT_HANDED = false;

  // Elecrow ships two display modules under one 2.13" part number: false is the SSD1680Z
  // panel, true the JD79661/EK79029 one. Pins, buttons and the visible area are identical,
  // the command set and BUSY polarity are not, so the wrong setting here shows a blank
  // screen and "Busy Timeout!" on serial.
  constexpr bool PANEL_JD79661 = true;

  // The JD79661 wants a 100ms reset pulse and has no software reset to fall back on;
  // GxEPD2's default of 10 is enough for the SSD1680.
  constexpr uint16_t EPD_RESET_DURATION_MS = PANEL_JD79661 ? 100 : 10;

  // EPD wiring (matches factory spi.h)
  constexpr int PIN_EPD_CS = 14;
  constexpr int PIN_EPD_DC = 13;
  constexpr int PIN_EPD_RST = 10;
  constexpr int PIN_EPD_BUSY = 9;
  constexpr int PIN_EPD_POWER = 7;

  // Physical button pins (align with factory mappings)
  constexpr int PIN_BTN_HOME = 2;
  constexpr int PIN_BTN_EXIT = 1;
  constexpr int PIN_BTN_PREV = 6;
  constexpr int PIN_BTN_NEXT = 4;
  constexpr int PIN_BTN_OK = 5;

  // Logical button mapping: what each UI action reads. Ok and Home are deliberately
  // crossed relative to the factory labels, so the central key is Ok.
  constexpr int PIN_OK = LEFT_HANDED ? PIN_BTN_EXIT : PIN_BTN_HOME;
  constexpr int PIN_EXIT = LEFT_HANDED ? PIN_BTN_HOME : PIN_BTN_EXIT;
  constexpr int PIN_PREV = LEFT_HANDED ? PIN_BTN_NEXT : PIN_BTN_PREV;
  constexpr int PIN_NEXT = LEFT_HANDED ? PIN_BTN_PREV : PIN_BTN_NEXT;
  constexpr int PIN_HOME = PIN_BTN_OK;
  // Deep sleep wake key. A physical pin, so the grip does not change it.
  constexpr int PIN_WAKE = PIN_BTN_OK;

  constexpr bool BUTTON_PULLUP = false;
  constexpr uint32_t BUTTON_DEBOUNCE_MS = 30;

  // Display and rendering
  constexpr uint8_t DISPLAY_ROTATION = LEFT_HANDED ? 1 : 3; // landscape
  constexpr uint8_t UI_TEXT_SIZE = 1;
  constexpr uint8_t READER_TEXT_SIZE = 1;
  constexpr int16_t UI_MIN_MARGIN = 4;
  constexpr uint8_t PARTIAL_REFRESH_LIMIT = 10;
  // Portal screen paints between full refreshes. It paints only on a change, so this
  // is a count of paints, not of seconds.
  constexpr uint16_t WIFI_SETTINGS_FULL_REFRESH_EVERY = 6;

  // Timing
  constexpr uint32_t SERVER_TIMEOUT_MS = 15UL * 60UL * 1000UL;
  constexpr uint32_t INACTIVITY_SLEEP_MS = 1UL * 60UL * 1000UL;
  constexpr uint32_t LONG_PRESS_MS = 900UL;
  constexpr uint32_t FS_FORMAT_HOLD_MS = 2500UL;

  // Below this there is nothing to gain from entering light sleep.
  constexpr uint64_t LIGHT_SLEEP_MIN_US = 20000ULL;

  // Keep this much filesystem space free for progress files and metadata
  constexpr uint32_t FS_RESERVE_BYTES = 64UL * 1024UL;

  // WiFi access point
  constexpr const char* WIFI_SSID = "TinyReader";
  constexpr const char* WIFI_PASS = "12345678";
  // Pinned rather than left to the default, so a failed join is reproducible.
  constexpr uint8_t WIFI_AP_CHANNEL = 1;
  constexpr uint8_t WIFI_AP_MAX_CONN = 2;

  // Storage paths
  constexpr const char* BOOKS_DIR = "/books";
  constexpr const char* PROGRESS_DIR = "/progress";
  constexpr const char* CURRENT_BOOK_FILE = "/current.txt";

  // Reader buffer size (bytes) used for raw reads per page
  constexpr int READ_BUFFER_SIZE = 512;

  // How many page positions to keep for backwards navigation
  constexpr size_t READER_HISTORY_MAX = 64;

  // Battery (set pin to valid ADC input to enable)
  constexpr int BATTERY_ADC_PIN = -1;
  constexpr float BATTERY_ADC_REF = 3.3f;
  constexpr int BATTERY_ADC_MAX = 4095;
  constexpr float BATTERY_DIVIDER = 2.0f;
  constexpr float BATTERY_MIN_V = 3.2f;
  constexpr float BATTERY_MAX_V = 4.2f;
}

// A panel class is a type, so this selector cannot be a ternary like the ones above.
// Both classes compile; the linker drops the unused one.
using EpdDriver = typename std::conditional<Config::PANEL_JD79661,
                                            GxEPD2_213_JD79661,
                                            GxEPD2_213_GDEY0213B74>::type;
using EpdDisplay = GxEPD2_BW<EpdDriver, EpdDriver::HEIGHT>;

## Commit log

2026-05-08 Add buttons opening on the left and shorten model to make buttons exit
    [crowpanel_2-13_case_3d.scad]
2026-05-09 Adjust usb position and smaller bezel size
    [crowpanel_2-13_case_3d.scad]
2026-05-09 Better usb opening (round and trapezoidal)
    [crowpanel_2-13_case_3d.scad]
2026-05-09 Slope on the border of the screen
    [crowpanel_2-13_case_3d.scad]
2026-05-09 Rename some variables
    [crowpanel_2-13_case_3d.scad]
2026-05-09 Make generic rounded_trapezoid module
    [crowpanel_2-13_case_3d.scad]
2026-05-10 Allow to have different radius in base one and two in trapezoid
    [crowpanel_2-13_case_3d.scad]
2026-05-10 Improve rounded trapezoid interface
    [crowpanel_2-13_case_3d.scad]
2026-05-10 Rounder buttons cutout
    [crowpanel_2-13_case_3d.scad]
2026-05-10 Adjust sizes with board model comparison
    [crowpanel_2-13_case_3d.scad]
2026-05-10 Rounded top border
    [crowpanel_2-13_case_3d.scad]
2026-05-10 Rounder base with module
    [crowpanel_2-13_case_3d.scad]
2026-05-20 Fix measures in scad file
    [crowpanel_2-13_case_3d.scad]
2026-05-21 Adjust case sizes, add splitting facilitator opening on base
    [crowpanel_2-13_case_3d.scad]
2026-05-21 Adjust case height, add toothpick holes for reset and boot buttons
    [crowpanel_2-13_case_3d.scad]
2026-05-26 Update ui with more complex flow
2026-05-26 New UI and button debounce
2026-05-26 Remove useless checks and fix menu states
    [Config.h, Input.cpp]
2026-05-26 Restore book choose button handlers
2026-05-26 Set battery pin
2026-05-27 Use serif font for text (with dynamic text size, big problems here)
    [Config.h]
2026-05-28 Add latin-1 encoding and glyphs support
    [crowpanel_2-13_case_3d.scad]
2026-06-02 Update README with clearer battery specs
2026-06-11 Init button covers
    [tiny_reader_2-13_case.scad]
2026-06-15 Lever button cover
    [tiny_reader_2-13_case.scad]
2026-06-15 Add more space for battery with smoothed cut
    [tiny_reader_2-13_case.scad]
2026-06-16 Increase tolerance of buttons
    [tiny_reader_2-13_case.scad]
2026-06-16 Adjust lever button (still not perfect)
    [tiny_reader_2-13_case.scad]
2026-06-16 Remove useless space for better fit
    [tiny_reader_2-13_case.scad]
2026-06-16 Reduce left bezel for more screen visibility
    [tiny_reader_2-13_case.scad]
2026-06-16 Visualize 3 way navigation switch size
    [tiny_reader_2-13_case.scad]
2026-06-16 Reduce side buttons cover height
    [tiny_reader_2-13_case.scad]
2026-06-16 Increase movement of lever button
    [tiny_reader_2-13_case.scad]
2026-06-17 Wider buttons
    [tiny_reader_2-13_case.scad]
2026-06-18 Adjust surface for the lever cover for less friction
    [tiny_reader_2-13_case.scad]
2026-06-18 Convert some internal rounded part to squares to improve printability
    [tiny_reader_2-13_case.scad]
2026-06-18 Refactor lever button code and make it a little bit taller
    [tiny_reader_2-13_case.scad]
2026-06-23 Change deep sleep exit button to central ok button (harder to trigger accidently)
2026-08-20 Normalize text on upload, fix index delete when power finished on page turn
    [partitions.csv]
2026-08-20 More responsive inputs (use interrupts and avoid losing clicks when display is refreshing)
    [Config.h, Input.cpp, tiny-reader.ino]
2026-08-21 Fix total space size, better buttons debouncing
    [partitions.csv]
2026-08-21 Fix display on newer board
    [Config.h, GxEPD2_213_JD79661.h, tiny-reader.ino]
2026-08-21 Better buttons debounce
2026-10-14 Store compressed books via opt-in client-side bzip2
    Books uploaded through the portal can be compressed in the browser
    (compressjs, served at /bz.js) into a TRZ1 container: one independent
    bzip2 stream per 400KB text chunk with a front index for page-level random
    access. BookFile presents the container as plain text so pagination,
    progress and history keep using uncompressed offsets; decompression runs
    in PSRAM (board option PSRAM=opi links the qio_opi SDK) behind a
    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
2026-10-14 Source libbz2 and compressjs from the flake
    libbz2 becomes a flake-built Arduino library wrapping nixpkgs' pinned
    bzip2 tarball (packages.bz2-library, include <bzlib.h>), so the sketch
    carries no vendored sources and --gc-sections still drops the unused
    compression paths. compressjs is pinned via fetchFromGitHub
    (packages.compressjs) so bundle regeneration is hermetic; the committed
    Bzip2Js.h regenerates byte-identical from the pin. flake.lock unchanged.
2026-10-14 Extract the upload page and add a keep-line-breaks option
    The portal page moves from a raw literal in WebPortal.cpp to
    src/upload.h, framed as one raw string literal so a plain #include
    pastes it in at the initializer; the .h name is load-bearing because
    the build copies only source types into its sketch copy. A keepbreaks
    checkbox opts out of the paragraph joining: single newlines survive and
    runs collapse to one, matching the already-unwrapped path. Default
    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
